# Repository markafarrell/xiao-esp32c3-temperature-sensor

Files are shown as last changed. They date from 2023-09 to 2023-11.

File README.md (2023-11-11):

### Requirements

* [esptool](https://pypi.org/project/esptool/)
* [micropython]( https://micropython.org/download/esp32c3/)
* [mpremote](https://github.com/dhylands/rshell)

## Flash Firmware

1. Install esptool

```
pip install esptool
```

2. Get circuitpython

```
mkdir -p micropython
cd micropython
curl -O https://micropython.org/resources/firmware/ESP32_GENERIC_C3-20230426-v1.20.0.bin
```

3. Start ESP32C3 in bootloader mode (hold down boot button while powering up)

4. Identify serial device

```
sudo dmesg | grep "USB ACM device" | tail -1
```

```
[24659.642354] cdc_acm 1-1:1.0: ttyACM0: USB ACM device
```

5. Erase flash

```
esptool.py --chip esp32c3 --port /dev/ttyACM0 erase_flash
```

6. Flash circuit python firmware

```
esptool.py --chip esp32c3 --port /dev/ttyACM0 --baud 460800 write_flash -z 0x0 micropython/ESP32_GENERIC_C3-20230426-v1.20.0.bin
```

### Install

1. Install requests

```
mpremote a0 mip install requests
```

2. Install application

```
mpremote a0 cp src/secrets.py :secrets.py
mpremote a0 cp src/sensor_mapping.py :sensor_mapping.py
mpremote a0 cp src/main.py :main.py
```

3. Run application

```
mpremote a0 run src/main.py
```

## Monitor Serial

### Connect

```
mpremote a0
```

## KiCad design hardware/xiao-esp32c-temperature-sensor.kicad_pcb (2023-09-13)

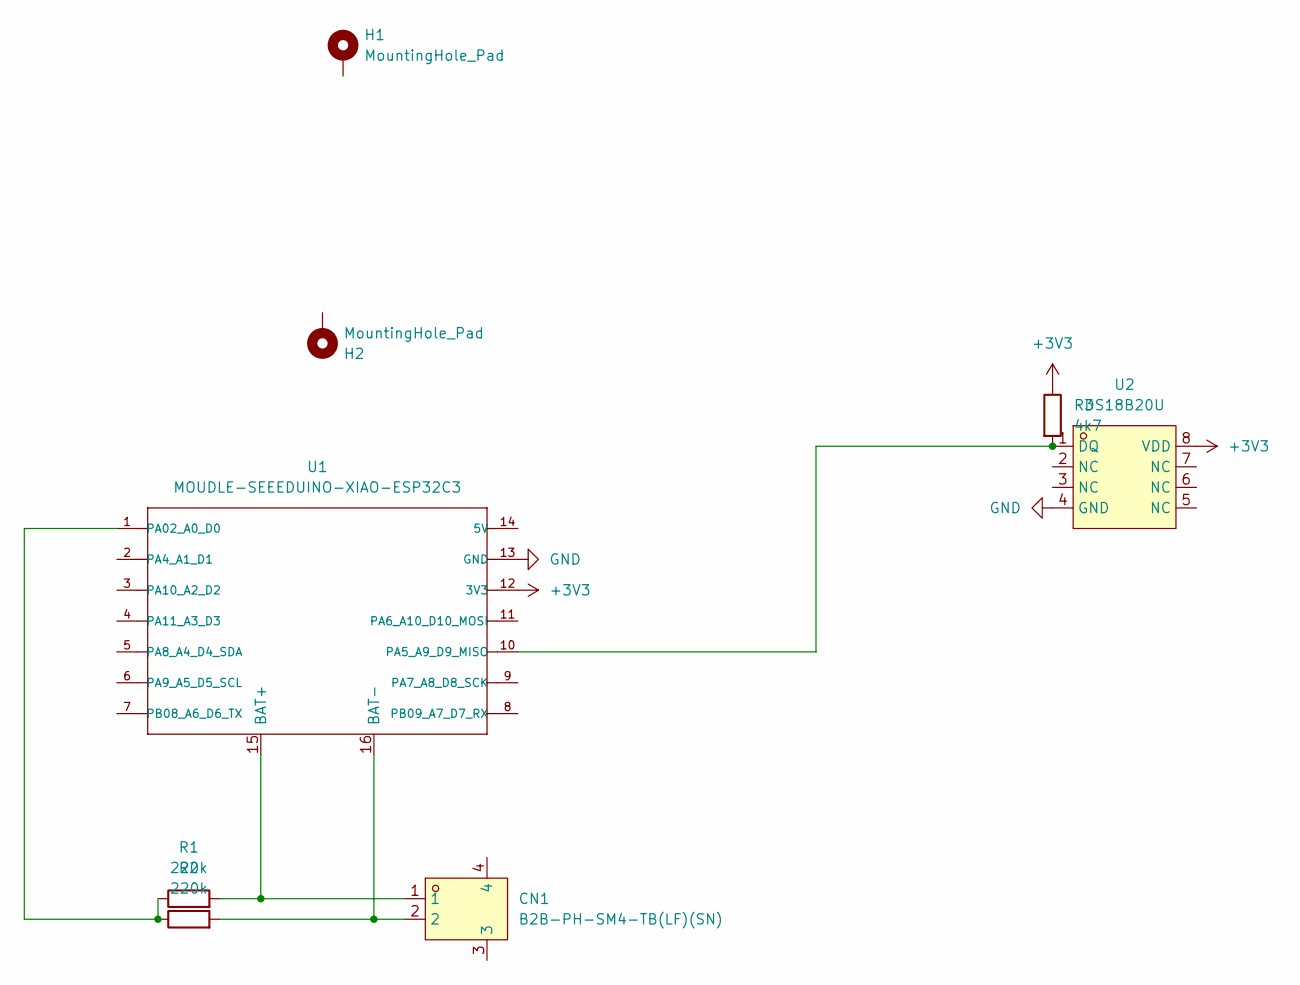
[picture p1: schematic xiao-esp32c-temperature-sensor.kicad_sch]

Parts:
CN1: B2B-PH-SM4-TB(LF)(SN); CONN-SMD_B2B-PH-SM4-TB-LF-SN; LCSC Part C160352
H1, H2: MountingHole_Pad; MountingHole_2.2mm_M2_DIN965_Pad
R1, R2: 220k; R_0805_2012Metric_Pad1.20x1.40mm_HandSolder
R3: 4k7; R_0805_2012Metric_Pad1.20x1.40mm_HandSolder
U1: MOUDLE-SEEEDUINO-XIAO-ESP32C3; MOUDLE14P-SMD-2.54-21X17.8MM-bat
U2: DS18B20U; MSOP-8_L3.0-W3.0-P0.65-LS4.9-BL; LCSC Part C695836

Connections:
+3V3: R3.1, U1.12 (3V3), U2.8 (VDD)
GND: U1.13 (GND), U2.4 (GND)
unnamed: CN1.1, R1.2, U1.15 (BAT+)
unnamed: CN1.2, R2.2, U1.16 (BAT-)
unnamed: R1.1, R2.1, U1.1 (PA02_A0_D0)
unnamed: R3.2, U1.10 (PA5_A9_D9_MISO), U2.1 (DQ)

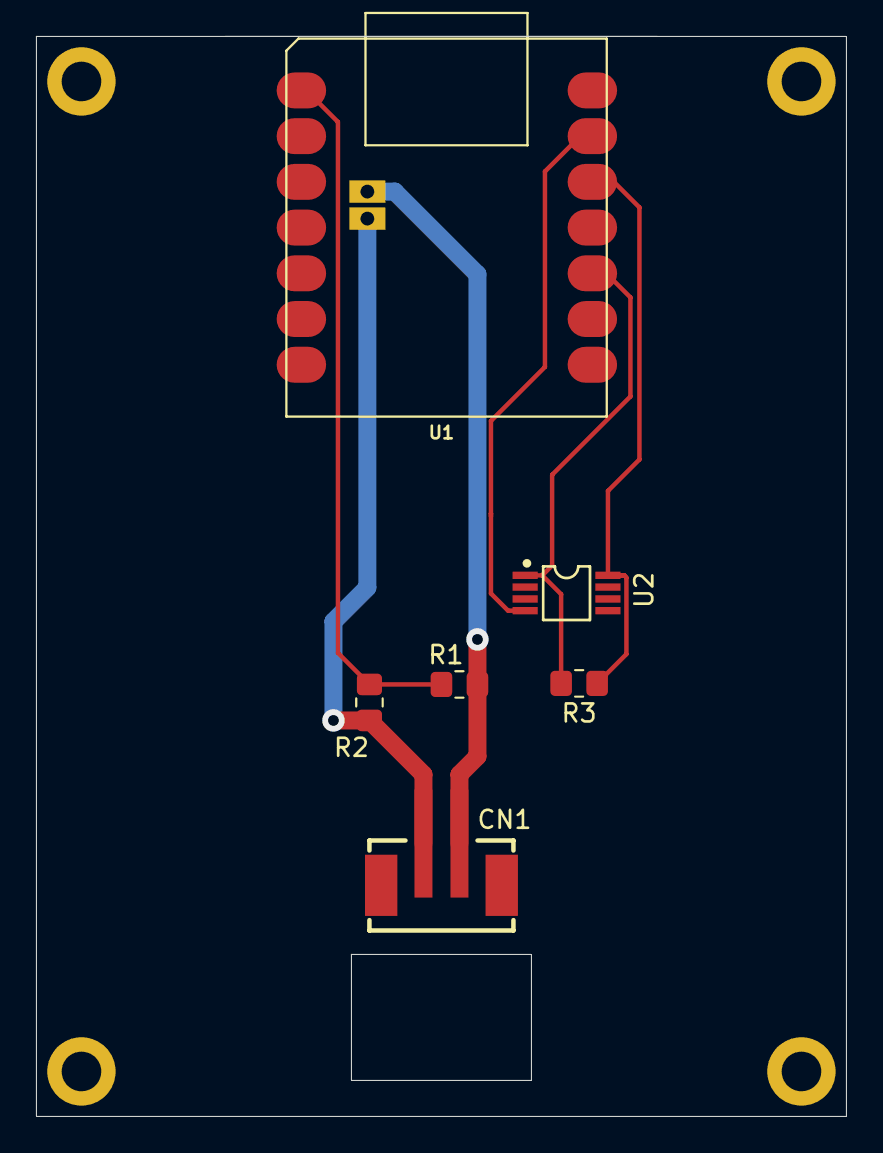
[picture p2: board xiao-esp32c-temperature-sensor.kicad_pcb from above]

Board: 2 copper layers, 45.0 x 60.0 mm, 10 parts (0 on the bottom side), 6 nets.

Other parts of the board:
H3, H4: MountingHole_Pad; MountingHole_2.2mm_M2_DIN965_Pad

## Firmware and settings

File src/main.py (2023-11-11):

import time
import machine
import onewire, ds18x20

import requests
import network

import secrets
import sensor_mapping

max_valid_temperature = 50
min_valid_temperature = -10

def pushMetric(pushgateway_url, job, name, value, type=None, labels=[]):
    '''
    cat <<EOF | curl --data-binary @- http://pushgateway.example.org:9091/metrics/job/some_job/instance/some_instance
    # TYPE some_metric counter
    some_metric{label="val1"} 42
    # TYPE another_metric gauge
    # HELP another_metric Just an example.
    another_metric 2398.283
    EOF
    '''
    data = ''

    if type is not None:
        data = data + f'# TYPE {name} {type}\n'

    label_data = ''
    first_label = True
    for label in labels:
        if not first_label:
            label_data = label_data + ','
        first_label = False
        label_data = label_data + f'{label["label"]}="{label["value"]}"'

    data = data + f'{name}{{{label_data}}} {value}\n'

    print(f'Pushing metric {data}')

    try:
        r = requests.post(
            f'{pushgateway_url}/metrics/job/{job}',data=data)
        r.close()
        del(r)
    except Exception as ex:
        print(f'Could not publish metric. {ex}')

sta_if = network.WLAN(network.STA_IF)
sta_if.active(True)

if sta_if.isconnected():
    sta_if.disconnect()

print(f'Connecting to WiFi')
sta_if.connect(secrets.wifi_ssid, secrets.wifi_password)

while not sta_if.isconnected():
    print('.', end='')
    time.sleep(0.1)
print()

pushgateway_url = 'http://192.168.0.99:9091'

# Read battery voltage from GPIO2 A0
bat_pin = machine.Pin(2)

bat = machine.ADC(bat_pin, atten=machine.ADC.ATTN_11DB)

# We need to have a compensation factor for each board as the resistors
# in the voltage divider are not exactly the same value
# Multiplying the adc voldate by this factor will get us the actual
# battery voltage
voltage_divider_compensation_factor = 1.789
bat_voltage = bat.read_uv() / 1e6 * voltage_divider_compensation_factor

# the device is on GPIO9 D9
dat = machine.Pin(9)

# create the onewire object
ds = ds18x20.DS18X20(onewire.OneWire(dat))

# scan for devices on the bus
roms = ds.scan()

ds.convert_temp()
for rom in roms:
    rom_hex = ''.join('{:02x}'.format(x) for x in rom)
    print(f'found device: 0x{rom_hex}')

    temp = ds.read_temp(rom)
    if temp > max_valid_temperature or temp < min_valid_temperature:
        print(f'invalid temperature(0x{rom_hex})={temp}')
        time.sleep(0.1)
    else:
        print(f'temperature(0x{rom_hex})={temp}')

        labels = [
            {
                "label": "ROM",
                "value": f'0x{rom_hex}'
            }
        ]

        if f'0x{rom_hex}' in sensor_mapping.sensor_mapping:
            location = sensor_mapping.sensor_mapping[f'0x{rom_hex}']
            print(f'found sensor mapping 0x{rom_hex})={location}')
            labels.append(
                {
                    "label": "Location",
                    "value": location
                }
            )

        pushMetric(
            pushgateway_url=pushgateway_url,
            job='ds18x20-exporter',
            name='ds18x20_temperature_celsius',
            value=temp,
            type='gauge',
            labels=labels
        )

        pushMetric(
            pushgateway_url=pushgateway_url,
            job='ds18x20-exporter',
            name='ds18x20_battery_voltage',
            value=bat_voltage,
            type='gauge',
            labels=labels
        )

        time.sleep(0.1)

# put the device to sleep
machine.deepsleep(900000) # 15 Minutes
